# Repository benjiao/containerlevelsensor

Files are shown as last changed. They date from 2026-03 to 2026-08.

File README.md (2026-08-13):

# Container Level Sensor
by Benjie Jiao

[][cc-by-sa]
[][ko-fi]

A DIY sensor for measuring the fill level of a container (e.g. our cat food bin),
based on an ESP32-C3 and a VL53L0x time-of-flight distance sensor, reporting
to Home Assistant over ESPHome.

For more info, check out the [build writeup][blog-post]. If this project was
useful to you, consider [buying me a coffee][ko-fi].

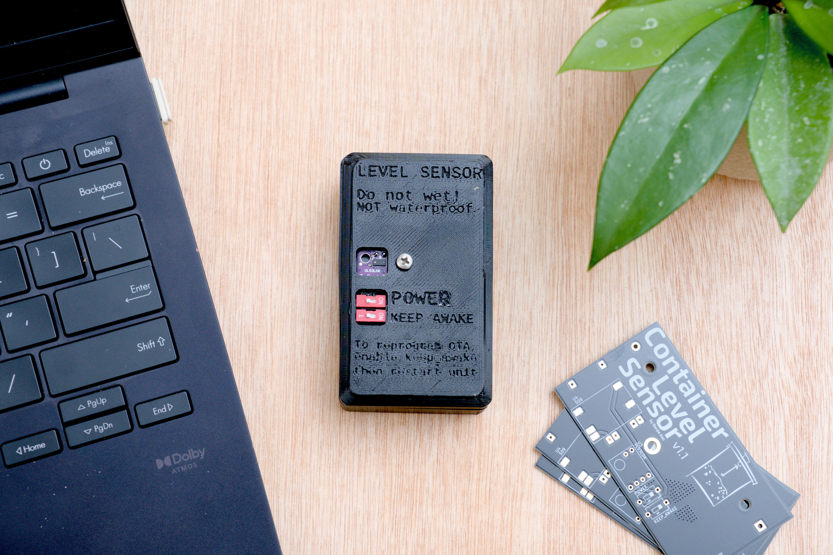
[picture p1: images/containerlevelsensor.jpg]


This is meant to be mounted under a container's lid. Like this prototype mounted to monitor our laundry basket.

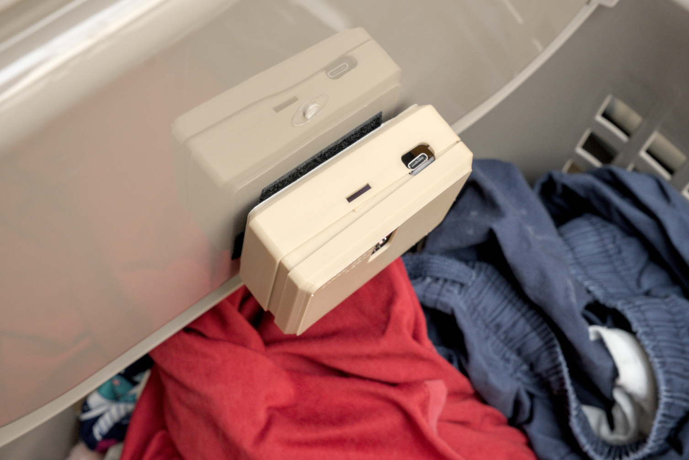
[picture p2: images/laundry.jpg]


## Repository contents

- `hardware/kicad/ContainerLevelSensor/` — KiCad project (schematic + PCB) for
  the sensor board. Open `ContainerLevelSensor.kicad_pro` in KiCad to view or
  edit the design.

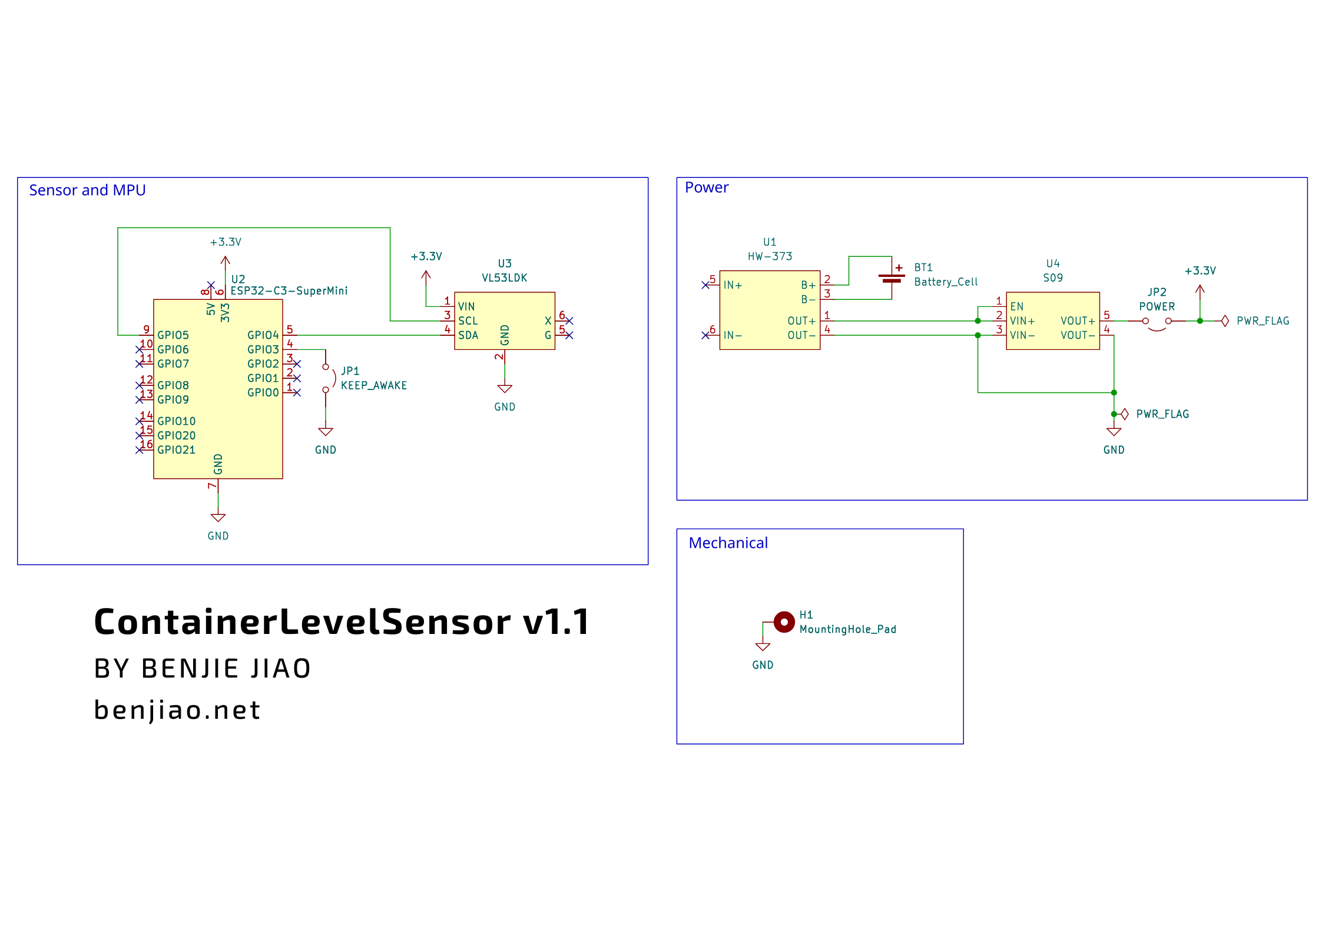
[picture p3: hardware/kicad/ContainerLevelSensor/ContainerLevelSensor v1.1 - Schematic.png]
Schematic
  
- `hardware/kicad/Fabrication/` — Generated Gerber/drill files and a ready-to
  order `.zip`, for sending straight to a PCB fab (e.g. PCBWay).
- `hardware/openscad/ContainerLevelSensor.scad` — Parametric enclosure,
  generated with [YAPP_Box](hardware/openscad/YAPP_Box) (included as a git
  submodule — run `git submodule update --init --recursive` before opening
  the `.scad` file in OpenSCAD). `ContainerLevelSensor.stl` is the pre-rendered
  mesh, ready to send to a 3D slicer as-is.
- `hardware/old_revisions/` — Earlier hardware revisions, kept for reference.
- `software/esphome/container-level.yaml` — [ESPHome](https://esphome.io)
  firmware configuration for the ESP32-C3. See "Flashing the firmware" below.

## Flashing the firmware

1. In Home Assistant, install the [ESPHome add-on](https://esphome.io/guides/getting_started_hassio.html)
   from Settings → Add-ons → Add-on Store (search for "ESPHome"), then start it.
2. Open the ESPHome add-on's web UI (or the ESPHome dashboard panel in the
   sidebar) and add a new device, then replace its generated YAML with the
   contents of `software/esphome/container-level.yaml`.
3. The add-on manages Wi-Fi credentials and secrets for you — when prompted,
   enter your Wi-Fi SSID/password; these are stored in its own `secrets.yaml`.
4. Replace the placeholder `api.encryption.key` and `ota.password` values in
   the config with your own (the dashboard can generate these for you when
   creating the device).
5. Connect the ESP32-C3 board over USB to the machine running Home Assistant
   (or use "Wirelessly" for subsequent updates once initially flashed), then
   click **Install** in the ESPHome dashboard for that device.
6. Once flashed, the device auto-connects to Home Assistant via the ESPHome
   integration, exposing the raw `VL53L0x Distance` reading and a computed
   `Level` percentage.

The `Keep Awake Jumper` pin (GPIO3) holds the board awake for
reflashing/debugging; otherwise the board deep-sleeps between readings to
save battery. Adjust `bottom_distance` in the `Level` sensor's lambda to
match the distance (in meters) from the sensor to the bottom of your
container.

## License

This work is licensed under a
[Creative Commons Attribution-ShareAlike 4.0 International License][cc-by-sa].

[][cc-by-sa]

[cc-by-sa]: http://creativecommons.org/licenses/by-sa/4.0/
[cc-by-sa-image]: https://licensebuttons.net/l/by-sa/4.0/88x31.png
[cc-by-sa-shield]: https://img.shields.io/badge/License-CC%20BY--SA%204.0-lightgrey.svg
[blog-post]: https://benjiao.net/posts/catfood-level-sensor/
[ko-fi]: https://ko-fi.com/benjiao
[ko-fi-badge]: https://img.shields.io/badge/ko--fi-support-ff5e5b?logo=ko-fi&logoColor=white

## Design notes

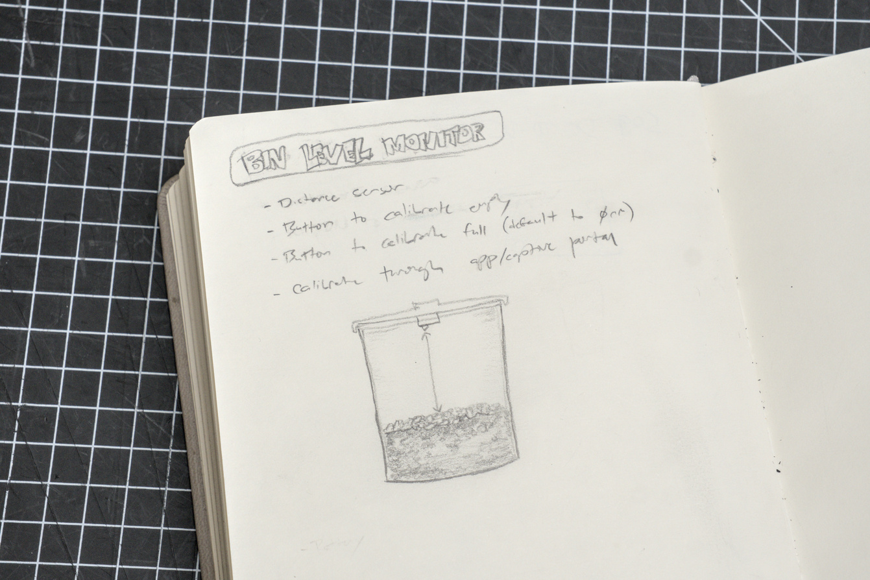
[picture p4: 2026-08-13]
images/rough-sketch.jpg

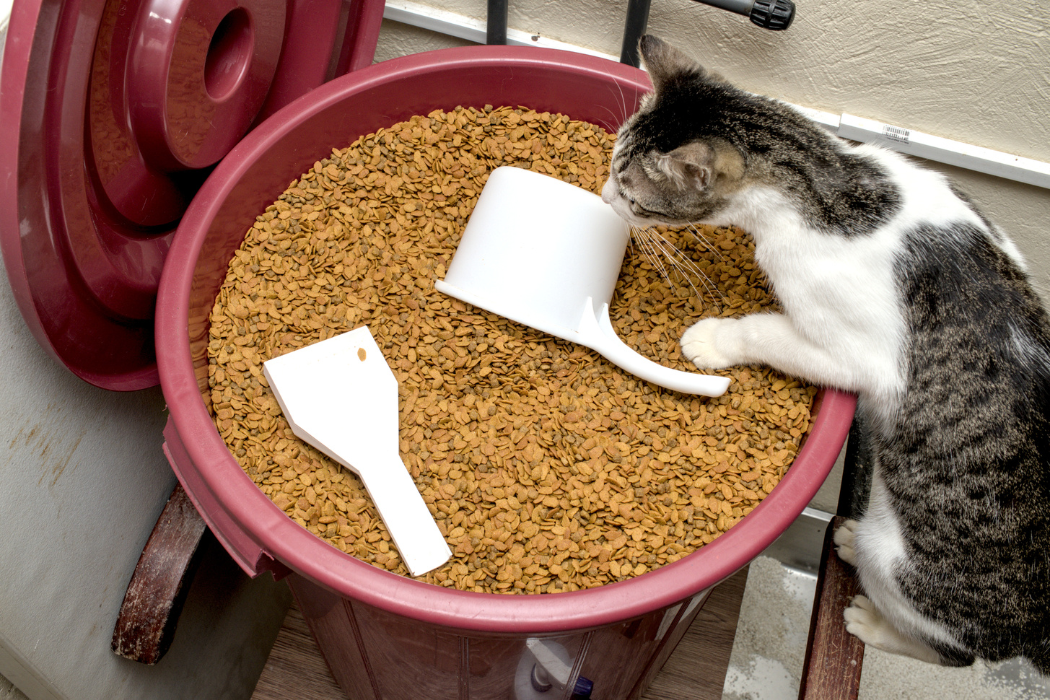
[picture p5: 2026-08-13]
images/catfood-bin.jpg

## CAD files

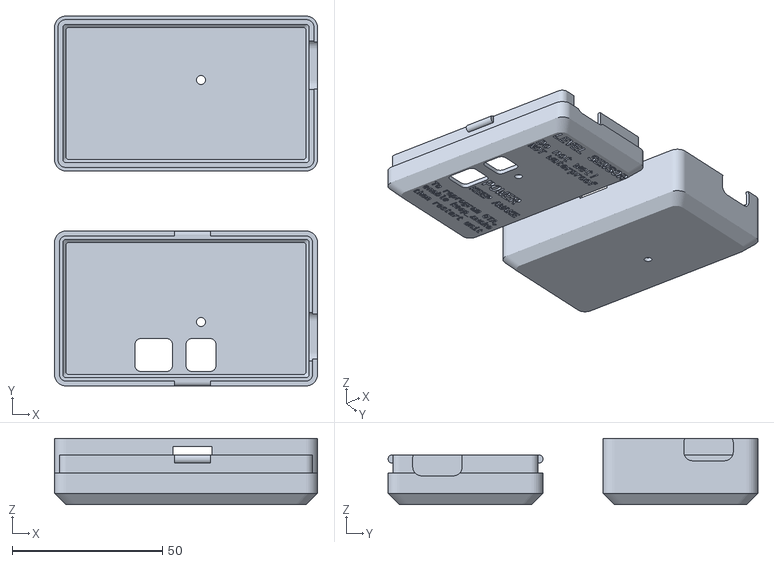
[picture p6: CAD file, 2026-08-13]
hardware/openscad/ContainerLevelSensor.stl
87.6 x 123.2 x 22.1

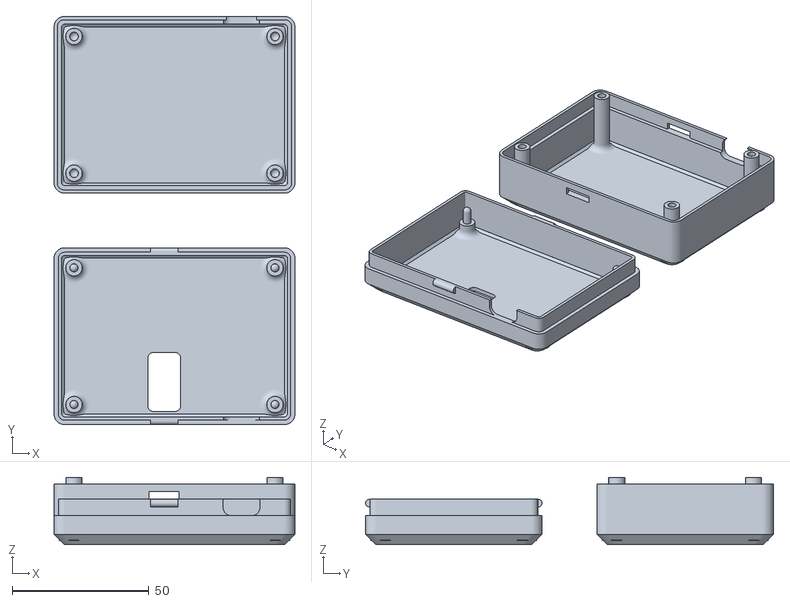
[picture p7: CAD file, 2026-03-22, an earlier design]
hardware/old_revisions/ContainerLevelSensor v1.0/openscad/ContainerLevelSensor.stl
88.1 x 149.2 x 24.6

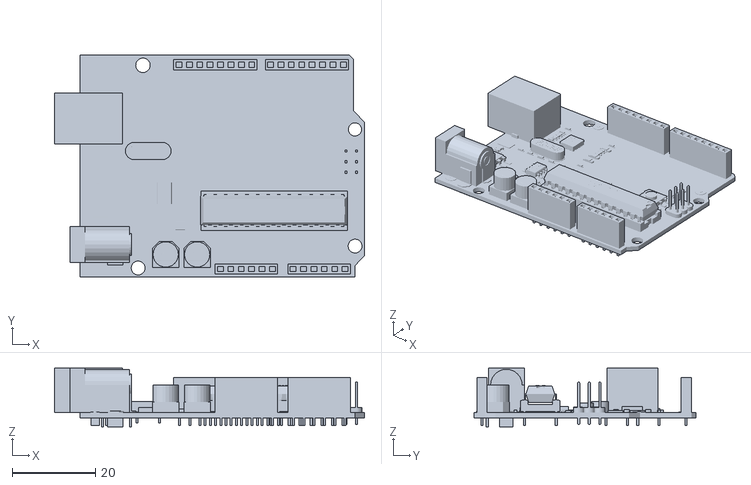
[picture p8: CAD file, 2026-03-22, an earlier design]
hardware/old_revisions/ContainerLevelSensor v1.0/openscad/YAPP_Box/STL/MODELS/Arduino_Uno_model.stl
74.6 x 53.3 x 14.2

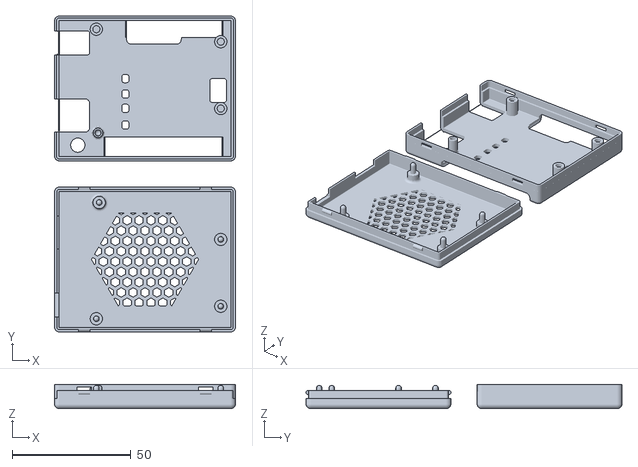
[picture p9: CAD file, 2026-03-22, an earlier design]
hardware/old_revisions/ContainerLevelSensor v1.0/openscad/YAPP_Box/STL/YAPP_ArduinoClone_v30.stl
76.1 x 132.8 x 10.2

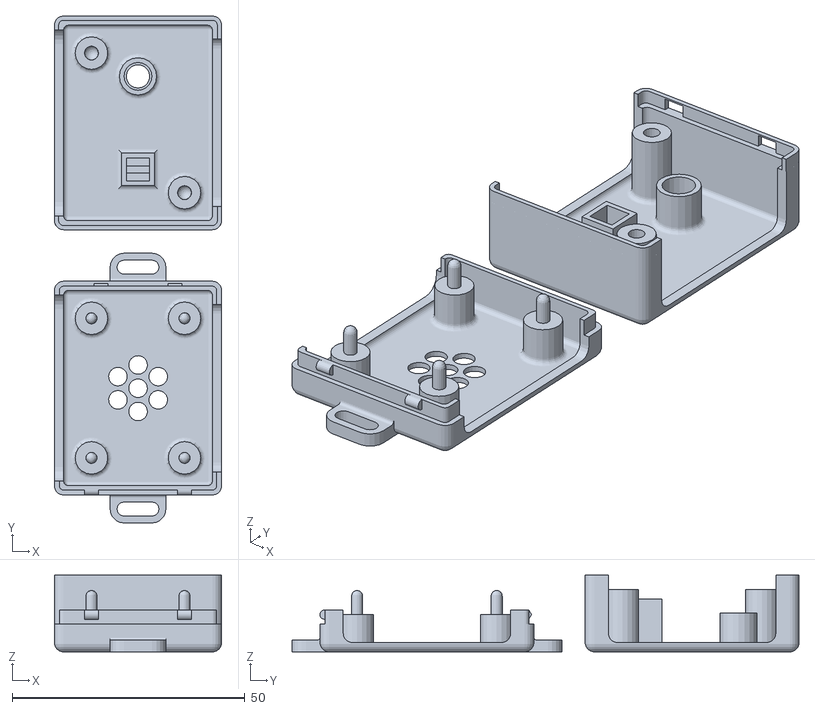
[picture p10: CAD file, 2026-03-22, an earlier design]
hardware/old_revisions/ContainerLevelSensor v1.0/openscad/YAPP_Box/STL/YAPP_Demo_lightTubes_v30.stl
36.0 x 109.0 x 16.5

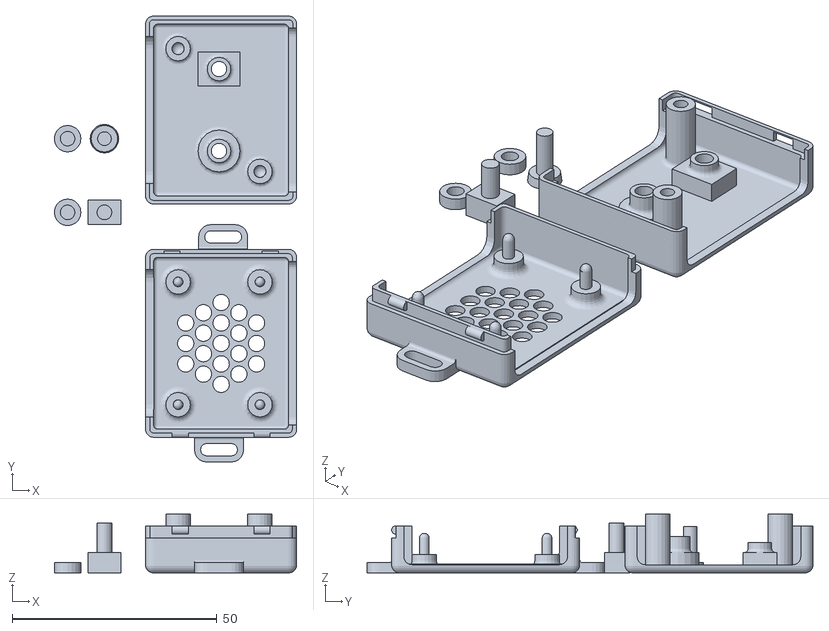
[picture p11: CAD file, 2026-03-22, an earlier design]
hardware/old_revisions/ContainerLevelSensor v1.0/openscad/YAPP_Box/STL/YAPP_Demo_buttons_v30.stl
59.2 x 109.0 x 14.4

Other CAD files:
hardware/openscad/ContainerLevelSensor.scad
hardware/old_revisions/ContainerLevelSensor v1.0/openscad/ContainerLevelSensor.scad
hardware/old_revisions/ContainerLevelSensor v1.0/openscad/YAPP_Box/YAPP_Template_v3.scad
hardware/old_revisions/ContainerLevelSensor v1.0/openscad/YAPP_Box/YAPPgenerator_v3.scad
hardware/old_revisions/ContainerLevelSensor v1.0/openscad/YAPP_Box/examples/ESP32-CAM-USB-FISH_v30.scad
hardware/old_revisions/ContainerLevelSensor v1.0/openscad/YAPP_Box/examples/ESP32-CAM-USB_v30.scad
hardware/old_revisions/ContainerLevelSensor v1.0/openscad/YAPP_Box/examples/GateAlarm_Sample_v30.scad
hardware/old_revisions/ContainerLevelSensor v1.0/openscad/YAPP_Box/examples/Multiple_PCB_v30.scad
hardware/old_revisions/ContainerLevelSensor v1.0/openscad/YAPP_Box/examples/PoolMonitor_v30.scad
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

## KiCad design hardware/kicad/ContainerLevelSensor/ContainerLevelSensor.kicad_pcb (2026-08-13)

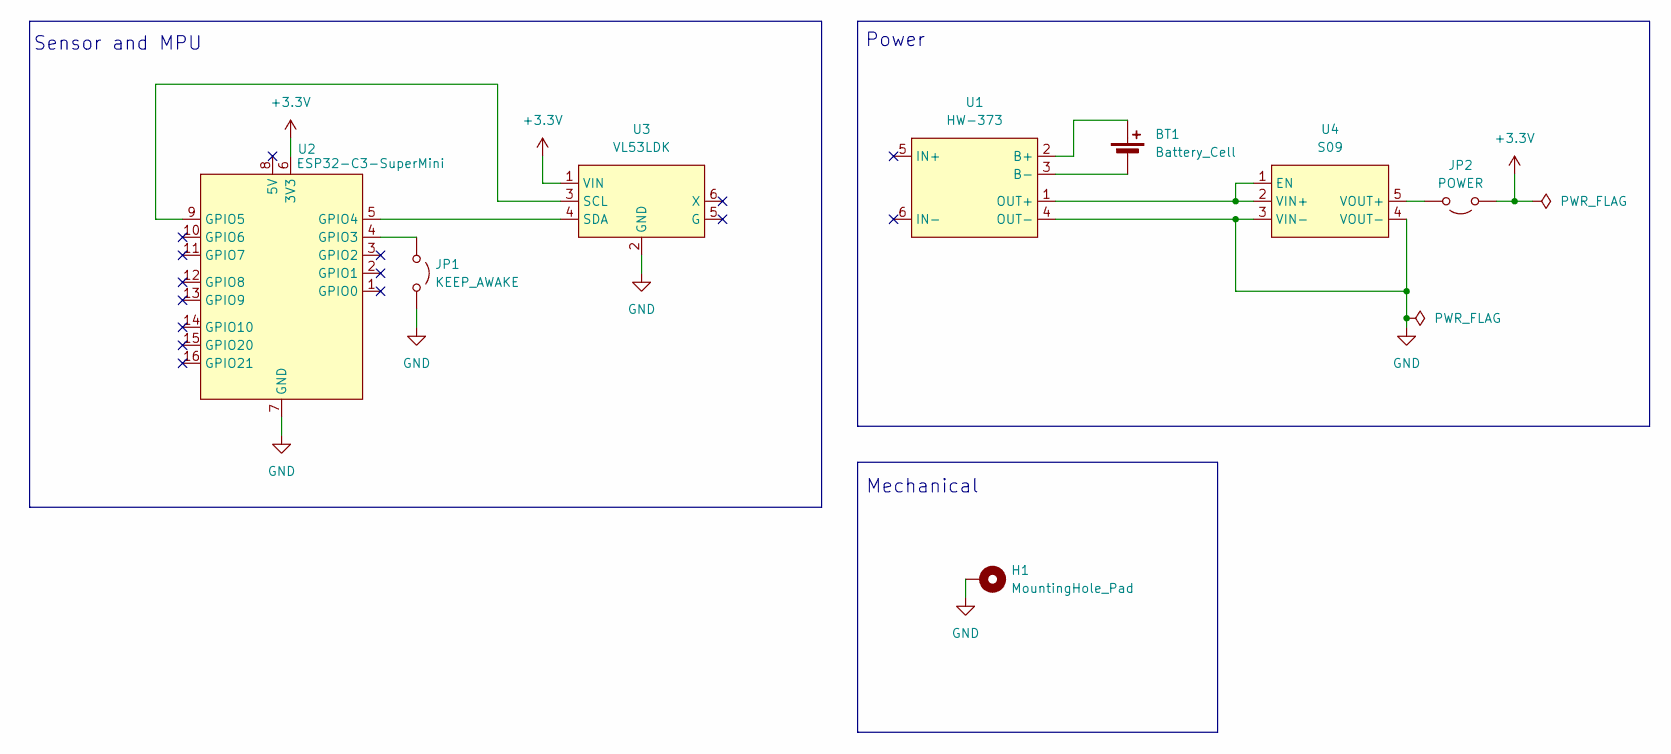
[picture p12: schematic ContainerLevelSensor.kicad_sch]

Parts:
BT1: Battery_Cell; BatteryHolder_MPD_BH-18650-PC
H1: MountingHole_Pad; MountingHole_3.2mm_M3_DIN965_Pad
JP1: KEEP_AWAKE; SW_DIP_SPSTx01_Slide_6.7x4.1mm_W7.62mm_P2.54mm_LowProfile
JP2: POWER; SW_DIP_SPSTx01_Slide_6.7x4.1mm_W7.62mm_P2.54mm_LowProfile
U1: HW-373; Module_HW-373_Li-Ion_Charging
U2: ESP32-C3-SuperMini; ESP32-C3-SuperMini_Edge
U3: VL53LDK; Module_VL53LDK_Distance_Sensor
U4: S09; Module_S09_DC_to_DC_Edge

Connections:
+3.3V: JP2.1 (A), U2.6 (3V3), U3.1 (VIN)
GND: H1.1, JP1.2 (B), U1.4 (OUT-), U2.7 (GND), U3.2 (GND), U4.3 (VIN-), U4.4 (VOUT-)
unnamed: BT1.1 (+), U1.2 (B+)
unnamed: BT1.2 (-), U1.3 (B-)
unnamed: JP1.1 (A), U2.4 (GPIO3)
unnamed: JP2.2 (B), U4.5 (VOUT+)
unnamed: U1.1 (OUT+), U4.1 (EN), U4.2 (VIN+)
unnamed: U2.5 (GPIO4), U3.4 (SDA)
unnamed: U2.9 (GPIO5), U3.3 (SCL)

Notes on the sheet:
Sensor and MPU
Power
Mechanical

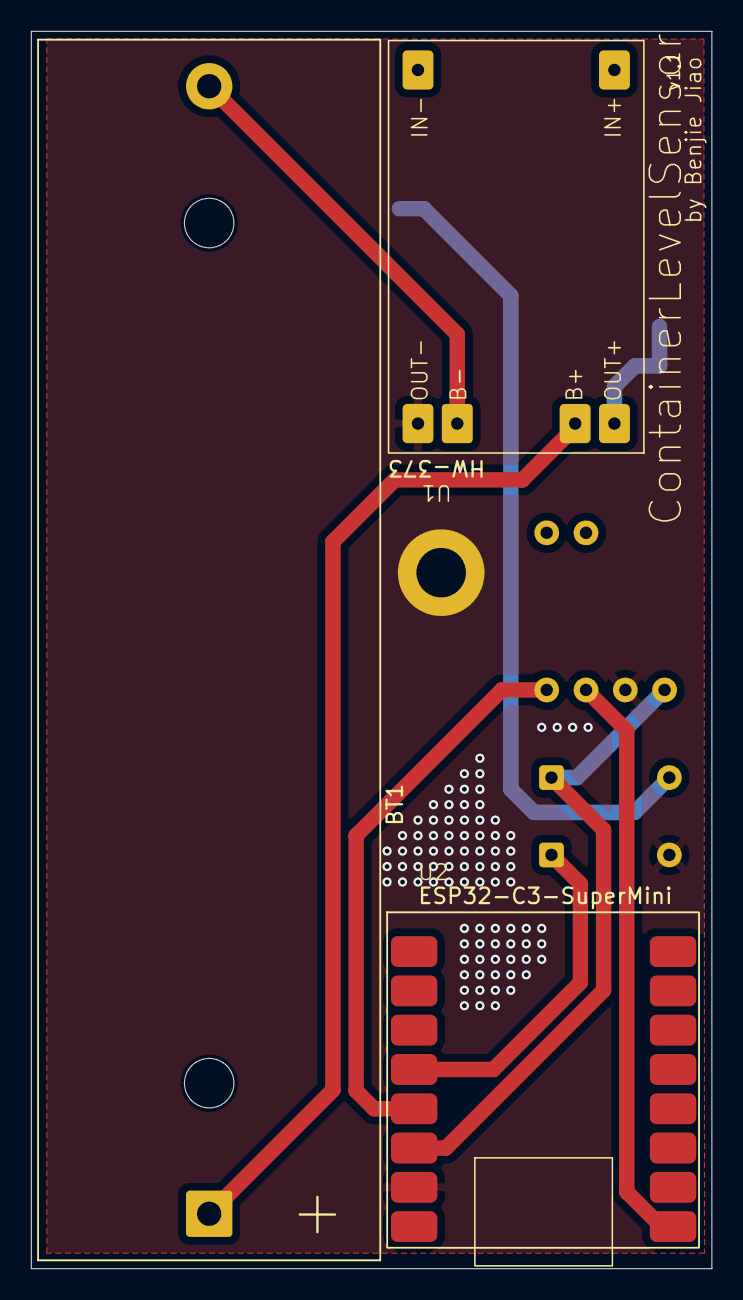
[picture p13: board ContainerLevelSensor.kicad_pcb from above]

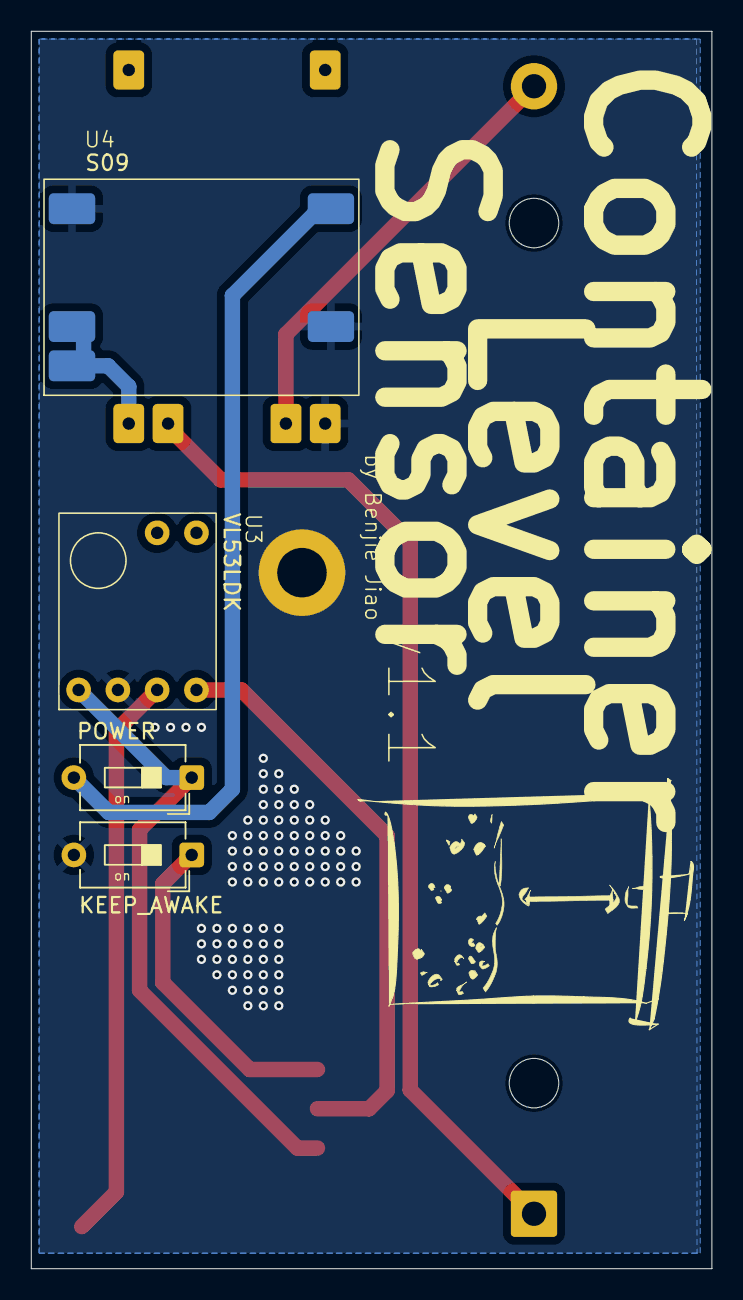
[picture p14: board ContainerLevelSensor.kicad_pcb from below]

Board: 2 copper layers, 44.0 x 80.0 mm, 8 parts (4 on the bottom side), 9 nets.

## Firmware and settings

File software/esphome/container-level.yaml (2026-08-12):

esphome:
  name: catfood-monitor
  friendly_name: Catfood Monitor
  on_boot:
    priority: -10
    then:
      - delay: 70s
      - if:
          condition:
            binary_sensor.is_off: keep_awake
          then:
            - deep_sleep.enter: ds

esp32:
  board: esp32-c3-devkitm-1
  framework:
    type: esp-idf

# Enable logging
logger:

# Enable Home Assistant API
api:
  encryption:
    key: "your-api-encryption-key"

ota:
  - platform: esphome
    password: "your-ota-password"

wifi:
  ssid: !secret wifi_ssid
  password: !secret wifi_password

  # Enable fallback hotspot (captive portal) in case wifi connection fails
  ap:
    ssid: "Catfood-Monitor Fallback Hotspot"
    password: "make-your-own-captive-portal-password"

captive_portal:
i2c:
  sda: GPIO04
  scl: GPIO05
  scan: true
  id: bus_a

binary_sensor:
  - platform: gpio
    id: keep_awake
    name: "Keep Awake Jumper"
    pin:
      number: GPIO3
      mode: INPUT_PULLUP
      inverted: true
      
deep_sleep:
  id: ds
  sleep_duration: 1h
sensor:
  - platform: vl53l0x
    id: sensor_distance
    name: "VL53L0x Distance"
    address: 0x29
    long_range: true
    update_interval: 15s
    
  - platform: template
    name: "Level"
    unit_of_measurement: "%"
    accuracy_decimals: 1
    update_interval: 15s
    lambda: |-
      static float bottom_distance = 0.52;
      static float top_offset = 0.1;
      float dist = id(sensor_distance).state;

      if (isnan(dist)) {
        return NAN;
      }

      float value = 100.0f * (1.0f - (dist - top_offset) / (bottom_distance - top_offset));
      return min(100.0f, max(0.0f, value));

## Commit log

2026-02-26 added version 1 files
    [ContainerLevelSensor-B_Cu.gbr, ContainerLevelSensor-B_Mask.gbr, ContainerLevelSensor-B_Paste.gbr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]
2026-02-26 Added readme and license
    [ContainerLevelSensor-B_Cu.gbr, ContainerLevelSensor-B_Mask.gbr, ContainerLevelSensor-B_Paste.gbr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]
2026-03-22 Added v1.1
    [Arduino_Uno_model.stl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]
2026-04-05 Added version 1.1
    [ContainerLevelSensor-B_Cu.gbr, ContainerLevelSensor-B_Mask.gbr, ContainerLevelSensor-B_Paste.gbr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]
2026-08-13 updated case
    [ContainerLevelSensor.kicad_pcb, ContainerLevelSensor.scad, ContainerLevelSensor.stl]
2026-08-13 Added images
    [ContainerLevelSensor.scad]

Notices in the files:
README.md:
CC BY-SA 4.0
